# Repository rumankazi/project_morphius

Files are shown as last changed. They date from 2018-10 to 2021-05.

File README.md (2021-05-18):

# Project Morphius
The final year project of students of Electronics and Telecommunication department at Sardar Patel Institute of Technology, Mumbai.

An open source project under the guidance of Prof. Dr. Preetida V. Jani. 

Here you will find the required code files, design files, assembly and respective instructions.

Follow us on youtube: https://www.youtube.com/channel/UCsKmAn2daWavVmRRQK_fTjw

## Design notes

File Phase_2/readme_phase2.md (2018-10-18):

Arduino folder contains files required for testing. Also contains final code required for interfacing app and base module.

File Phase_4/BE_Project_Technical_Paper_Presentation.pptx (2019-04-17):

## Morphius

Self-configuring modular robot that navigates through cracks and debris for inspection

## Problem Statement

Use of modular robots for rescue operations involve constraints on parameters such as speed, size, shape of robot, locomotion mechanisms, etc. This requires development and design of a MRS that optimizes the above parameters. The use of heterogeneous modules capable of self-reconfiguration improves speed of locomotion and resourcefulness at the cost of simplicity.

## Existing Technology

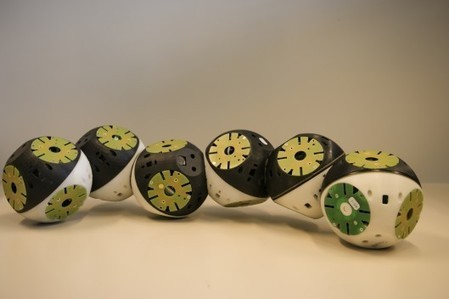
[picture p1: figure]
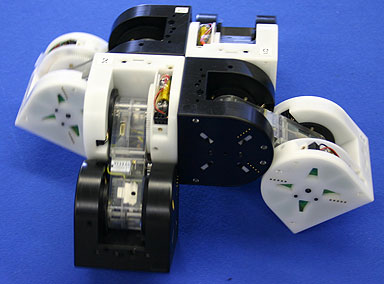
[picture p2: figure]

M-Tran - III

RoomBots

## Comparison

Existing Technology | Our technology
Relatively homogenous modules lacking in functionality | Heterogenous modules - tailored for use in disaster struck areas
Not practically deployable | Practically deployable
Designed for generalized applications - performance degrades | Problem oriented approach - provides better results
Expensive | Cost effective

## Limitations

- Not suited for rescue operations in disasters - earthquake, hurricane
- Difficult to deploy in disaster struck areas
- Less cost effective technology
- Not adaptable to different types of terrain or obstacles
- Lack decision making capability

## Proposed Solution

- Heterogenous modules - different functions tailored for our application
- Autonomous & self- reconfigurable
- Robust design for rough environment
- Providing map of the disaster struck area
- Adapts to the different terrain using different morphology

## Robotic System Structure

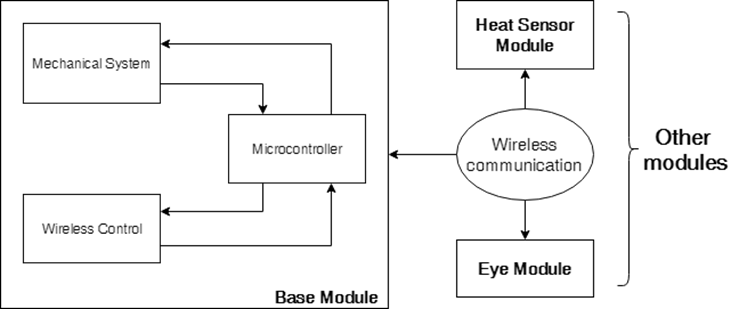
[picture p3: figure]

## Base Module Architecture

## Secondary Module Architecture

## Hardware & Software Assembly

Hardware:
- Atmega2560, Arduino Nano
- Wi-Fi
- Motor -
  - geared, 10kg stall torque, 100rpm
  - geared, quadrature encoder, 150rpm
  - Servo - 7kg at 1.5A, 6V
  - Micro DC motor - geared, 5kg torque
- Motor driver - L298n, L293d
- Bevel gears - 3D printed
- Wheels: 6.5cm, 10.9cm
- Pi Camera - 5MP

Software:
- Autodesk Fusion 360
- AutoCAD
- Opencv - python library
- Aruco - python library
- ArUco markers - 3cm x 3cm, 5x5 matrix size

## Aruco Detection

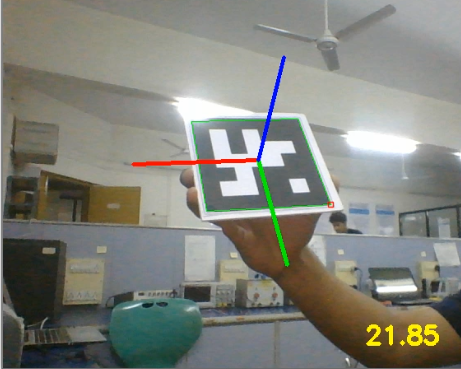
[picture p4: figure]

## Linking Mechanism

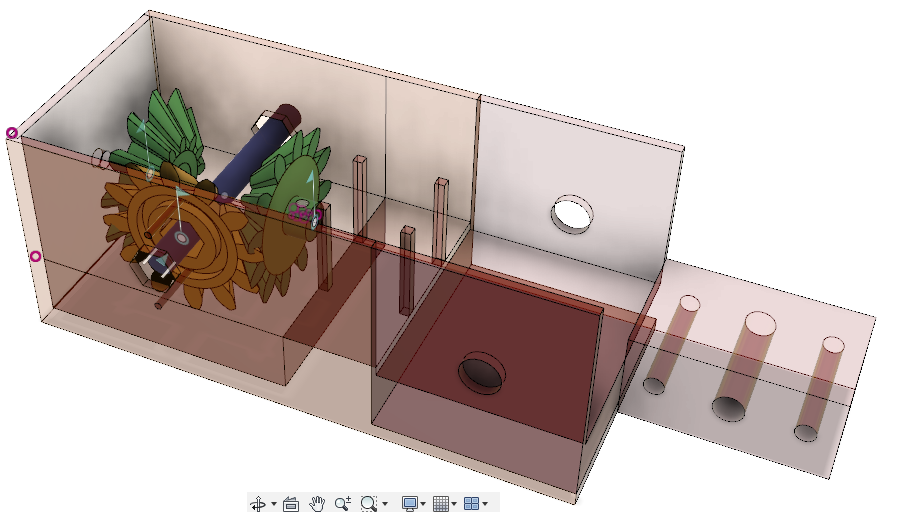
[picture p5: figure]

- 3 bevel gears - 3D printed
- 1 geared DC motor, 1 Servo motor
- Genderless connector - bolt

## Linking Mechanism

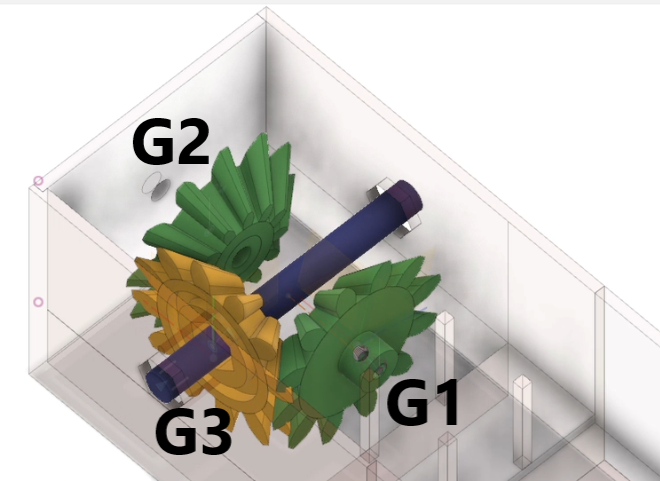
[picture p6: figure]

Closed Screw Mechanism

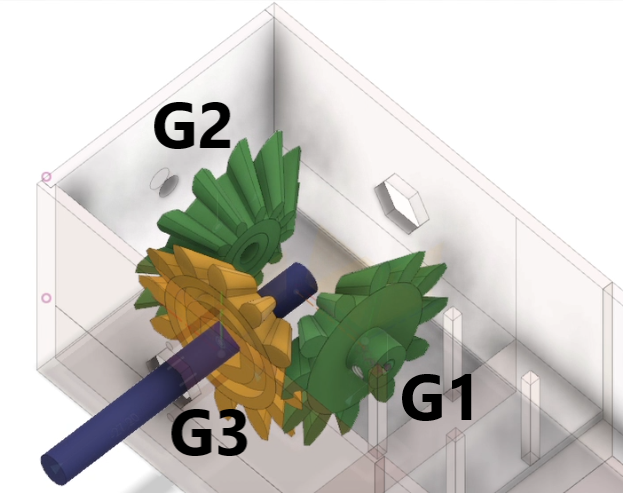
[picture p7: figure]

Open Screw Mechanism

## Result Analysis

- Tradeoff between size and speed for motors and wheels
- Alignment of wheels for stability and speed enhancement
- Sturdier actuation mechanism with minimum constraint
- Detection and alignment of modules for connection
- Chances of misalignment while engaging
- Size of the markers has to be minimized according to the smallest module

## Conclusion

- Speedy-modular-robots have potential to be used in rescue operations
- Speed control possible using PWM
- Decision making capability has been added to the modules
- ArUco Markers have improved the accuracy of alignment of two modules.
- Machine Learning can be used to improve performance over the period
- Sturdy modular design for rough terrains ensure protection of sensors

## Future Scope

- Using machine learning for configuration
- Improving the linking mechanism design and making it compact
- Using cloud for data collection and remote monitoring
- Development of different modules with different sensors

## Morphius Accessibility

Entire project is open source and is accessible to everyone.
All the instructions and required files are regularly updated on github and can be easily accessed using the following link:
https://github.com/rumankazi/project_morphius
YouTube Channel:
https://www.youtube.com/channel/UCsKmAn2daWavVmRRQK_fTjw

## References

1. M. Yim, D. G. Duff, and K. Roufas, “Modular reconfigurable robots, an approach to urban search and rescue,” in Proceedings of the 1st International Workshop on Human-friendly Welfare Robotics Systems, Taejon, Korea, 2000.
2. H. Ahmadzadeh, E. Masehian, and M. Asadpour, “Modular robotic systems: characteristics and applications,” Journal of Intelligent & Robotic Systems, vol. 81, no. 3-4, pp. 317–357, 2016.
3. H. Kurokawa, K. Tomita, A. Kamimura, S. Kokaji, T. Hasuo, and S. Murata, “Distributed self-reconfiguration of m-tran iii modular robotic system,” The International Journal of Robotics Research, vol. 27, no. 3-4, pp. 373–386, 2008.
4. J. Davey, N. Kwok, and M. Yim, “Emulating self-reconfigurable robots design of the smores system,” in 2012 IEEE/RSJ International Conference on Intelligent Robots and Systems (IROS). IEEE, 2012, pp. 4464–4469.
5. C. S. S. Reddy, A. Agrawal, K. Anupama et al., “Sq-bot-a modular robot prototype for self-reconfiguring structures,” in International Conference on Robotics: Current Trends and Future Challenges (RCTFC),. IEEE, 2016, pp. 1–6.

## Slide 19

6. J. Zhao, X. Cui, Y. Zhu, and S. Tang, “A new self-reconfigurable modular robotic system ubot: Multi-mode locomotion and self-reconfiguration,” in 2011 IEEE International Conference on Robotics and automation (ICRA). IEEE, 2011, pp. 1020–1025.
7. A. Spr¨owitz, R. Moeckel, M. Vespignani, S. Bonardi, and A. J. Ijspeert, “Roombots: A hardware perspective on 3d self-reconfiguration and locomotion with a homogeneous modular robot,” Robotics and Autonomous Systems, vol. 62, no. 7, pp. 1016–1033, 2014.
8. S. Chitta and J. Ostrowski, “Motion planning for heterogeneous modular mobile systems,” in ICRA’02. IEEE International Conference on Robotics and Automation, 2002. Proceedings., vol. 4. IEEE, 2002, pp. 4077–4082.
9. G. Hu, S. Huang, L. Zhao, A. Alempijevic, and G. Dissanayake, “A robust rgb-d slam algorithm,” in 2012 IEEE/RSJ International Conference on Intelligent Robots and Systems. IEEE, 2012, pp. 1714–1719.
10. “Raspberry Pi 3 Model B - Raspberry Pi.” [Online]. Available: https://www.raspberrypi.org/products/raspberry-pi-3-model-b/

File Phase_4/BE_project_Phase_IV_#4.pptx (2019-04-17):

## Morphius

Self-configuring modular robot that navigates through cracks and debris for inspection

## Problem Statement

Use of modular robots for rescue operations involve constraints on parameters such as speed, size, shape of robot, locomotion mechanisms, etc. This requires development and design of a MRS that optimizes the above parameters. The use of heterogeneous modules capable of self-reconfiguration improves speed of locomotion and resourcefulness at the cost of simplicity.

## Objectives

●Study of existing MRS (Phase 1)
●Development & Designing the structure of MRS (Phase 1-2-3)
●Inter-module mechanical connection Mechanism (Phase 3)
●Wireless Communication amongst the modules (Phase 2-3)
●Determining the best possible path and configuration (Phase 4)
●Improving the speed of MRS (Phase 4)

## Comparison

Existing Technology | Our technology
Relatively homogenous modules lacking in functionality | Heterogenous modules - tailored for use in disaster struck areas
Not practically deployable | Practically deployable
Designed for generalized applications - performance degrades | Problem oriented approach - provides better results
Expensive | Cost effective

## Robotic System Structure


## Base Module Architecture

## Secondary Module Architecture

## Limitations

- Not suited for rescue operations in disasters - earthquake, hurricane
- Difficult to deploy in disaster struck areas
- Less cost effective technology
- Not adaptable to different types of terrain or obstacles
- Lack decision making capability

## Proposed Solution

- Heterogenous modules - different functions tailored for our application
- Autonomous & self- reconfigurable
- Robust design for rough environment
- Providing map of the disaster struck area
- Adapts to the different terrain using different morphology

## Previous Work

- Backbone design of robot
- Working Prototype of base module
- Established wireless communication
- Power budgeting of single module
- Analysis of various connection mechanisms

## Previous Remarks

- Minimize the parameters to be controlled
- Weight Calculation
- Different wireless communication protocols testing
- Voltage v/s current rating for motors

## Progress Achieved - Phase 4

- Optimization of the design of the base module and secondary modules
- Selection of motors of locomotion with high stall torque (10kg)
- Prototype of connection mechanism
- 3D printing of the mechanism
- Image processing for identification and alignment
- Using Machine Learning for the terrain identification
- Study path planning and mapping algorithms

## Software Implementation

## Testing

Hardware:
- Atmega2560, Arduino Nano
- Bluetooth - HM10 , Xbee
- Motor -
  - geared, 10kg stall torque, 100rpm
  - geared, quadrature encoder, 150rpm
  - Servo - 7kg at 1.5A, 6V
  - Micro DC motor - geared, 5kg torque
- Motor driver - L298n, L293d
- Bevel gears - 3D printed
- Wheels -
  - (diameter)6.5cm, 10.9cm
  - Castor

Software:
- Autodesk Fusion 360
- AutoCAD
- Opencv - python library
- Aruco - python library
- ArUco markers - 14x14, 5x5 matrix size

## Actuation Mechanism


- 3 bevel gears - 3D printed
- 1 geared DC motor, 1 Servo motor
- Genderless connector - bolt

## Result Analysis

- Tradeoff between size and speed for motors and wheels
- Alignment of wheels for stability and speed enhancement
- Sturdier actuation mechanism with minimum constraint
- Detection and alignment of modules for connection
- Chances of misalignment while engaging
- Size of the markers has to be minimized according to the smallest module

## Further Planning

- Using machine learning for configuration
- Improving the linking mechanism design and making it compact
- Using cloud for data collection and remote monitoring
- Development of different modules with different sensors

## Morphius Accessibility

Entire project is open source and is accessible to everyone.
All the instructions and required files are regularly updated on github and can be easily accessed using the following link:
https://github.com/rumankazi/project_morphius
YouTube Channel:
https://www.youtube.com/channel/UCsKmAn2daWavVmRRQK_fTjw

## References

1. H. Ahmadzadeh, E. Masehian and M. Asadpour, "Modular Robotic Systems: Characteristics and Applications", Springer, Dordrecht, 2015.
2. Stoy, Kasper & Brandt, David & Christensen, David. (2010). Self-Reconfigurable Robots: An Introduction.
3. Haruhisa Kurokawa,Kohji Tomita, Akiya Kamimura, Shigeru Kokaji, Takashi Hasuo,Satoshi Murata , "Distributed Self-Reconfiguration of M-TRAN III Modular Robotic System ," in International Journal of Robotics March 2008
4. Jay Davey, Ngai Kwok and Mark Yim, "Emulating Self-reconfigurable Robots - Design of the SMORES System " in 2012 IEEE/RSJ International Conference on Intelligent Robots and Systems
5. Jie Zhao, Xindan Cui, Yanhe Zhu, et al. “A new self-reconfigurable modular robotic system UBot: Multi-mode locomotion and self-reconfiguration,” IEEE International Conference on Robotics and Automation. Piscataway, NJ, USA , pp. 1020-1025, 2011.
6. H. Ercan and P. Boyraz, "Design of a Modular Mobile Multi Robot System: ULGEN (Universal-Generative Robot)", IEEE Xplore, 2016.

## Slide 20

7. C. S. S. Reddy, S. patlolla, A. Agrawal and K. R. Anupama, "SQ-BOT - a modular robot prototype for self-reconfiguring structures," 2016 International Conference on Robotics: Current Trends and Future Challenges (RCTFC), Thanjavur, 2016, pp. 1-6.
8. S. Chitta and J. R. Ostrowski, "Motion planning for heterogeneous modular mobile systems," Proceedings 2002 IEEE International Conference on Robotics and Automation (Cat. No.02CH37292), Washington, DC, USA, 2002, pp. 4077-4082 vol.4
9. Andres Castano Wei-Min Shen Peter Will, "CONRO: Towards Deployable Robots with Inter-Robots Metamorphic Capabilities, " in Autonomous Robots June 2000, Volume 8, Issue 3, pp 309–324
10. R. Fitch, Z. Butler, D. Rus, "Reconfiguration planning for heterogeneous self-reconfiguring robots, " in 2003 IEEE/RSJ International Conference on Intelligent Robots and Systems (IROS 2003)
11. Shimizu, T. Kato, M. Lungarella and A. Ishiguro, "Adaptive Reconfiguration of a Modular Robot through Heterogeneous Inter-Module Connections", IEEE Xplore, 2008.

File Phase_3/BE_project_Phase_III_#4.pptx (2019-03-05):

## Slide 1

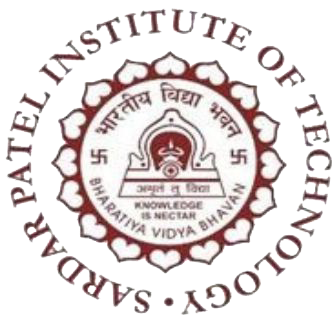
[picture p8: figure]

Sardar Patel Institute of Technology

Electronics and Telecommunication Department

B.E Project (ETP701)
Stage 2

Morphius : Self-reconfiguring modular robot that navigates through cracks and debris for inspection

A project under the guidance of
Dr. Preetida V-Jani

Group Number 4
Ruman Kazi
Ameya Nambisan
Simran Tiwari

## Problem Statement

Use of modular robots for rescue operations involve constraints on parameters such as speed, size, shape of robot, locomotion mechanisms, etc. This requires development and design of a MRS that optimizes the above parameters. The use of heterogeneous modules capable of self-reconfiguration improves speed of locomotion and resourcefulness at the cost of simplicity.

## Objectives

●Study of existing MRS (Phase 1)
●Development & Designing the structure of MRS (Phase 1-2-3)
●Inter-module mechanical connection Mechanism (Phase 3)
●Wireless Communication amongst the modules (Phase 2-3)
●Determining the best possible path and configuration (Phase 4)
●Improving the speed of MRS (Phase 4)

## Comparison

Existing Technology | Our technology
Relatively homogenous modules lacking in functionality | Heterogenous modules - tailored for use in disaster struck areas
Not practically deployable | Practically deployable
Designed for generalized applications - performance degrades | Problem oriented approach - provides better results
Expensive | Cost effective

## Robotic System Structure


## Base Module Architecture

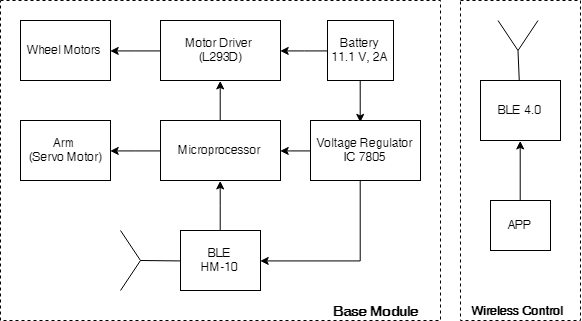
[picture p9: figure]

## Limitations

- Not suited for rescue operations in disasters - earthquake, hurricane
- Difficult to deploy in disaster struck areas
- Less cost effective technology
- Not adaptable to different types of terrain or obstacles
- Lack decision making capability

## Proposed Solution

- Heterogenous modules - different functions tailored for our application
- Autonomous & self- reconfigurable
- Robust design for rough environment
- Providing map of the disaster struck area
- Adapts to the different terrain using different morphology

## Previous Work

- Backbone design of robot
- Working Prototype of base module
- Established wireless communication
- Power budgeting of single module
- Analysis of various connection mechanisms

## Previous Remarks

- Minimize the parameters to be controlled
- Weight Calculation
- Different wireless communication protocols testing
- Voltage v/s current rating for motors

## Progress Achieved - Phase 3

- Optimization of the design of the base module
- Selection of motors of locomotion with high stall torque (10kg)
- Prototype of connection mechanism
- Image processing for identification and alignment
- Study path planning and mapping algorithms

## Actuation Mechanism


- 3 bevel gears - 3D printed
- 1 geared DC motor, 1 Servo motor
- Genderless connector - bolt

## Testing

Hardware:
- Atmega2560, Arduino Nano
- Bluetooth - HM10 , Xbee
- Motor -
  - geared, 10kg stall torque, 100rpm
  - geared, quadrature encoder, 150rpm
  - Servo - 7kg at 1.5A, 6V
  - Micro DC motor - geared, 5kg torque
- Motor driver - L298n, L293d
- Bevel gears - 3D printed
- Wheels -
  - (diameter)6.5cm, 10.9cm
  - Castor

Software:
- Autodesk Fusion 360
- AutoCAD
- Opencv - python library
- Aruco - python library
- ArUco markers - 14x14, 5x5 matrix size

## Result Analysis

- Tradeoff between size and speed for motors and wheels
- Alignment of wheels for stability and speed enhancement
- Sturdier actuation mechanism with minimum constraint
- Detection and alignment of modules for connection
- Chances of misalignment while engaging
- Size of the markers has to be minimized according to the smallest module

## Further Planning

- Phase 4 (First week of April):
  - Development of other connectable heterogeneous modules
  - Algorithm for deciding optimal path and configuration
  - Development of reconfiguration algorithm

## Morphius Accessibility

Entire project is open source and is accessible to everyone.
All the instructions and required files are regularly updated on github and can be easily accessed using the following link:
https://github.com/rumankazi/project_morphius
YouTube Channel:
https://www.youtube.com/channel/UCsKmAn2daWavVmRRQK_fTjw

## References

1. H. Ahmadzadeh, E. Masehian and M. Asadpour, "Modular Robotic Systems: Characteristics and Applications", Springer, Dordrecht, 2015.
2. Stoy, Kasper & Brandt, David & Christensen, David. (2010). Self-Reconfigurable Robots: An Introduction.
3. Haruhisa Kurokawa,Kohji Tomita, Akiya Kamimura, Shigeru Kokaji, Takashi Hasuo,Satoshi Murata , "Distributed Self-Reconfiguration of M-TRAN III Modular Robotic System ," in International Journal of Robotics March 2008
4. Jay Davey, Ngai Kwok and Mark Yim, "Emulating Self-reconfigurable Robots - Design of the SMORES System " in 2012 IEEE/RSJ International Conference on Intelligent Robots and Systems
5. Jie Zhao, Xindan Cui, Yanhe Zhu, et al. “A new self-reconfigurable modular robotic system UBot: Multi-mode locomotion and self-reconfiguration,” IEEE International Conference on Robotics and Automation. Piscataway, NJ, USA , pp. 1020-1025, 2011.
6. H. Ercan and P. Boyraz, "Design of a Modular Mobile Multi Robot System: ULGEN (Universal-Generative Robot)", IEEE Xplore, 2016.

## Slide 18

7. C. S. S. Reddy, S. patlolla, A. Agrawal and K. R. Anupama, "SQ-BOT - a modular robot prototype for self-reconfiguring structures," 2016 International Conference on Robotics: Current Trends and Future Challenges (RCTFC), Thanjavur, 2016, pp. 1-6.
8. S. Chitta and J. R. Ostrowski, "Motion planning for heterogeneous modular mobile systems," Proceedings 2002 IEEE International Conference on Robotics and Automation (Cat. No.02CH37292), Washington, DC, USA, 2002, pp. 4077-4082 vol.4
9. Andres Castano Wei-Min Shen Peter Will, "CONRO: Towards Deployable Robots with Inter-Robots Metamorphic Capabilities, " in Autonomous Robots June 2000, Volume 8, Issue 3, pp 309–324
10. R. Fitch, Z. Butler, D. Rus, "Reconfiguration planning for heterogeneous self-reconfiguring robots, " in 2003 IEEE/RSJ International Conference on Intelligent Robots and Systems (IROS 2003)
11. Shimizu, T. Kato, M. Lungarella and A. Ishiguro, "Adaptive Reconfiguration of a Modular Robot through Heterogeneous Inter-Module Connections", IEEE Xplore, 2008.

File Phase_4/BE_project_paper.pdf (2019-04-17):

# Morphius: A Self-configuring modular robot that navigates through cracks and debris for inspection

Abstract—Modular robots are made up of mechanically constrained smaller robots with different degrees of freedom. These smaller robots can either detach or attach together to get a desired structure or configuration. The existing technology in this field consists of robots with homogeneous modules that lack the decision making capability and are not currently applicable in disaster struck area for inspection.
To improve their performance, heterogeneity has been introduced in its structure making it possible to design versatile, application tailored modules having decision making capability. Each module will independently be able to perform a specific task depending on the attributes and given characteristics with self-configuring and reconfiguring capability. At the same time all the modules communicate and share their data with each other to collectively accomplish the goal. We have also introduced wheels for effective and faster locomotion and self-docking capability using a neutral connector. This paper addresses the two main challenges while developing such modular robotic system
- intelligence and speed, in the field of rescue operations with adaptive morphology.
Keywords—Modular robot, Self configurable, Heterogeneity, Self-docking, Wireless communication, Autonomous, ArUco markers.
I. INTRODUCTION

In the past two decades around 10 lakh deaths have been reported worldwide due to earthquakes, landslides, storms and hurricanes; almost 1.5 lakhs were only from India. Over 15% of these were late deaths - deaths due to injuries that become prominent with the passage of time - could have been avoided had disaster management been more efficiently carried out. Doctors refer to this time as the golden hour, which is the period of time after a traumatic incident during which immediate medical assistance can save a person’s life. Some injuries like haemorrhage, brain injuries and internal bleeding deteriorate rapidly. So it is necessary to keep the time lag between injury and treatment bare minimum.
Rescue operations conducted worldwide mostly employ trained professionals and dogs. Equipment such as video cameras and high sensitivity listening devices are used in order to locate a person moving or responding to rescuers calls [1]. Depending on the scale of destruction, the process of extrication can extend over 24 hours. These environments pose a risk to even the lives of rescuers as there is imminent danger of a further collapse in event of an earthquake. Recent reports prove the usefulness of robots in these fields as they enable rescuers to analyse the environment remotely. They had better speed and did not require much manpower. But because of their large size and power requirements, these robots are not efficient enough. This is where the concept of multi robot systems can be used. Due to the increasing demands in functionality, adaptability and robustness engineering innovations brought forth the idea of multi robot systems - systems which work in a distributed manner to complete a task. Inspired by biological systems, scientists proposed the use of self organising modular robotic system [2].
Through this paper we try to overcome the problems related to intelligence, speed and increased locomotion. Morphius aims to deal with the surrounding environment specifically targeting disaster struck areas and would try to utilize its functions for the assisting the rescue operation.

II. LITERATURE SURVEY

The most important thing in a rescue operation is the speed at which the help arrives to the victims. Flexibility to reach the remote location is another key aspect which decides the efficiency rescue operations and rate at which the injured people are provided with medical care. The technology has been consistently evolving toward providing a solution for such scenarios. There have been multiple attempts to provide a robotic solution to such areas. There are key terms associated with such systems. The research is required to go through all the attempts that have been made and to step upon already developed solutions and rectify their limitations and faults to make them efficient and better the desired application.

A. Basic terminology & concepts related to MRS
To understand already developed series of modular robots, it is important to understand the key terms and definitions related to modular robotic systems (MRS). Modular Robotic Systems: Characteristics and Applications - A detailed report [2] covers overall terminology related to the MRS and also provides key insights in the domain of modular-robotics. The four fundamental components that define a modular robotic systems are ”Module, Information, Task and Environment (MITE)” [2]. This report also discusses about the problems associated with certain systems and their feasibility.
It is also necessary to classify the robotic system in standardized format depending on the four components (MITE) [2]. We can create different types of MRS by varying these components. There are about 94 [2] developed modular robots existing today each one having unique features and mechanism.
B. Existing MRS
Existing technologies include M-TRAN III [3], SMORES [4], SQ-BOT [5], UBot [6] among many others and have distinctive features like size, locomotion mechanism, structure, behaviour etc. Analysis of different existing modular robotic systems provides different perspective with which a particular problem was solved. Analysing the particular problem and designing the system accordingly by considering the variable, dependent and independent parameters is the key to get an optimum MRS. Following are two of the most advanced MRS existing today.
1) M-TRAN III: Design inspired by locomotion of reptiles, M-TRAN III [3] was developed in 2007 as a successor of M-TRAN II (2003) and original M-TRAN (2000). Homogeneous modules made of same shape and mechanism to connect. It uses most of modern technology of wireless communication through its different modules. The shape of each module gives M-TRAN [3] huge flexibility of different morphologies by combining itself with other similar modules.. Because of reptile locomotion, M-TRAN is comparatively slower than others.
2) Room Bots: EPFL University project developed for different morphology and heavy lifting. The design is sturdy, large and can hold up large weights. Room bots are helpful in heavy load lifting and can be used to transport heavy loads. Room bots [7] have lesser flexibility compared to M-TRAN III [3]. Because of the heavy torque lifting motors, room bots have to compromise on the size of each module. As the size increases, it reduces the probability of going through narrow holes and cracks.
M-TRAN III [3] compromised on speed to get more flexibility, whereas Room Bots compromised on size of each module to get more heavy lifting. Each modular robotic system has to find a balanced system to solve a certain problem. For a particular application we can compromise on the components that won’t affect the performance of the system as much. The existing systems are not deployable in practical environments due to constraints on their locomotion and/or structure. And those which can be employed in such conditions are either expensive, slow and lack the decision making capability. If we can provide a solution by bypassing such factors, we can achieve our desired goal.

III. SYSTEM DESIGN

The basic block diagram of Morphius’ modular robotic system is as shown in the figure 1. The number of modules to be included is variable and will be decided by the desired application. Currently we are working with one eye module for testing and prototyping purpose. But it can be extended to multiple modules having different sensors and actuators. This block diagram just represents how it will interact with the base module which will be driving the modules when necessary. The software part comprises of the use of 5x5 ArUco markers for identifying a particular module and also for aligning the module for proper linking. The pi-camera at the front of every module detects the ArUco marker on the module it needs to be attached to. The marker is used for uniquely identifying the module, calculate its distance and estimate its

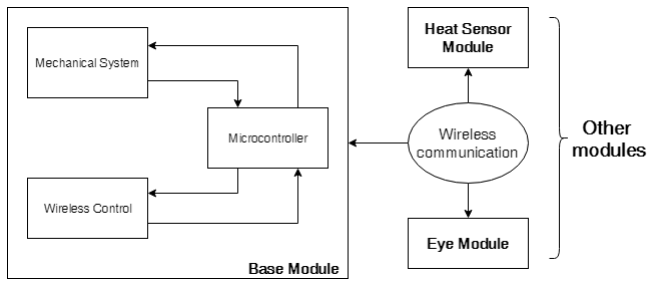
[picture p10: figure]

Fig. 1: Block diagram of the system

pose. This information is used to align the modules as they come closer to each other to be linked.
The eye module consists of a camera with high resolution. This camera is primarily used for mapping the area besides helping the robot to plan its path [8]. This is done using a visual Simultaneous Localisation And Mapping (SLAM) algorithm [9]. A set of points in the Region Of Image (ROI) are tracked through successive frames to estimate the relative position of the module so that it creates a map of its surrounding terrain. Images from the camera can also be monitored in real time on the network. The eye module is also used to identify the type of terrain and determine whether it can move forward or not. The module is trained to identify the terrain using classification with the help of a convolutional neural network.

IV. HARDWARE ASSEMBLY

The block diagram of configuration of components involved in base module is as shown in the figure 2a. The base module includes microprocessor to control the base module which receives signal from other modules (Figure 2b) via WiFi. The dimensions of this module are bigger compared to the other module so that it is stable enough to lift other modules linked together. The structure of the modules are made out of 3mm acrylic sheets and the mechanical connection mechanism is 3D printed out of Polylactic acid (PLA) fiber. The basic components used are:
- Motors:
– DC gear motor with 100 RPM and a high stalling torque was used for the base module. For other modules this is replaced by low torque compact motors.
– A servo motor having high torque of 5KG used for arm mechanism such that it can lift heavy modules. In case of eye module servo will also be used to pan the camera.
– Micro gear DC motor with 100 RPM and a high torque for the linking mechanism.
- Microprocessor:
– Raspberry Pi model 3B [10] which has a Quad Core 1.2GHz Broadcom BCM2837 64bit CPU [10] was used as our central processor.

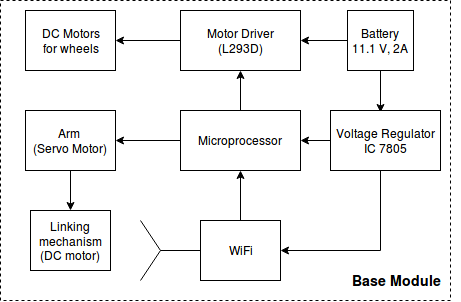
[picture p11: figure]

(a) Base module

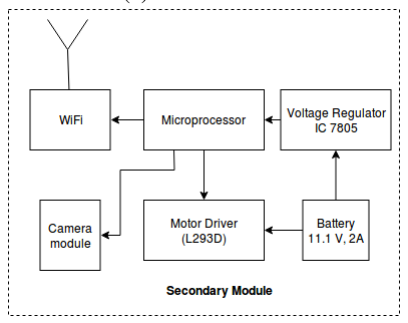
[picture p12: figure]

(b) Secondary Module

Fig. 2: Block Diagrams of the modules

– Controls pwm for Servo and Wheel motors. Also receives messages through WiFi. It also implements machine learning and image processing for aligning the modules.
– This board was chosen as CPU for each module for the machine learning and image processing to be done through python. We can use any PyBoard having python modules and opencv libraries.
- Battery:
– Lithium-Ion rechargeable battery providing 11.1V and 2Amps of current
– Used as power of source for entire module and will power servo, microprocessor, motor driver, Wi-Fi and respective sensors.
- Voltage Regulator:
– IC7805 was used to provide 5V supply to the microprocessor from the supply of 11.1V battery
– Also provides supply to DC motors used for wheels and Servo Motor
- WiFi:
– In-built WiFi on the Raspberry Pi 3B model was used for communication.
– Better than Bluetooth in terms of coverage, connectivity and speed.
– Advantage is we can remotely access all the modules remotely once they are set on same network.
- ArUco Markers:
– Augmented Reality Marker (ArUco) is a marker consisting of black and white matrix denoting 0 and
1. And it can store information in this matrix (Figure 4)(4x4, 5x5, etc.).

– We are using 5x5 matrix with different IDs for identifying each module uniquely.
– These markers are also used for pose estimation and distance calculation between any two modules. These markers help each module to align themselves with respect to the other module.

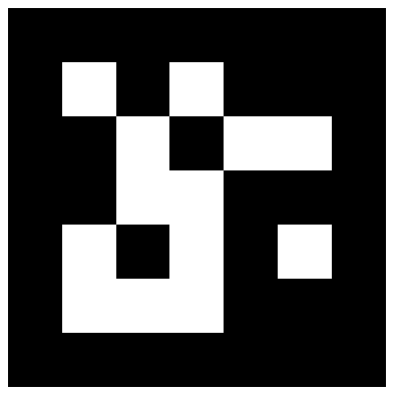
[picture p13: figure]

Fig. 3: An ArUco Marker of 5x5 Matrix with ID = 0

- Camera
– A pi-camera used by all modules and would be used for detection of aruco markers. And then it will send signals to CPU, which will relay signals to motors for correct alignment with other module.
– A webcam or a camera with at least 2Mp resolution for mapping only on the eye module.
- IR sensor:
– For obstacle detection and path planning. It is also used to calculate the height of the obstacle.
- Wheels
– 106mm Diameter and 44mm thick wheels for the base module to enhance the stability
– 70mm Diameter and 21mm thick wheels for the other modules to make them compact.
– Castor wheels for providing stability to the smaller modules.

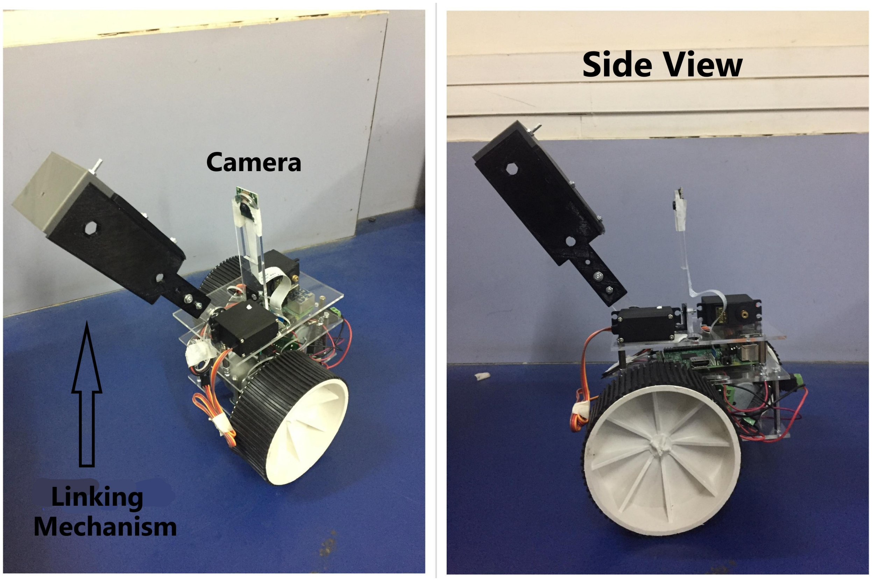
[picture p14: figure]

Fig. 4: Assembled Base Module with Linking Mechanism

V. LINKING MECHANISM
The key part of any Modular Robotic System(MRS) is its linking mechanism. Depending on the application of the MRS, the mechanism is decided. The key parameters involved while deciding a linking mechanism are:
- Weight of each module.
- Working environment.
- Size of the module.
- Algorithm for the configuration.
For Morphius, the surrounding environment is a rough terrain having uneven surfaces, debris and cracks. Also, Morphius should have maximum speed possible while traversing through such area. So, if we remove constraints on the size of the module and use high torque sturdy motors with strong body, we will require a physical linking mechanism to hold each module firmly throughout its operation.
The mechanism used has been shown in the figure 5. It comprises of three bevel gears(G1,G2 and G3) and one micro geared DC motor. The DC geared micro-motor is attached to one of the bevel gears(G1) which in turn rotates the main gear which has a bolt at its shaft. The rotating gear causes the bolt to move back and forth allowing it to lock into the arm of the other module. This entire mechanism is mounted inside a casing - 3D printed - using PLA material. Polylactic acid or PLA. This entire assembly is attached to a servo on the base module which helps align the arm in the z direction.

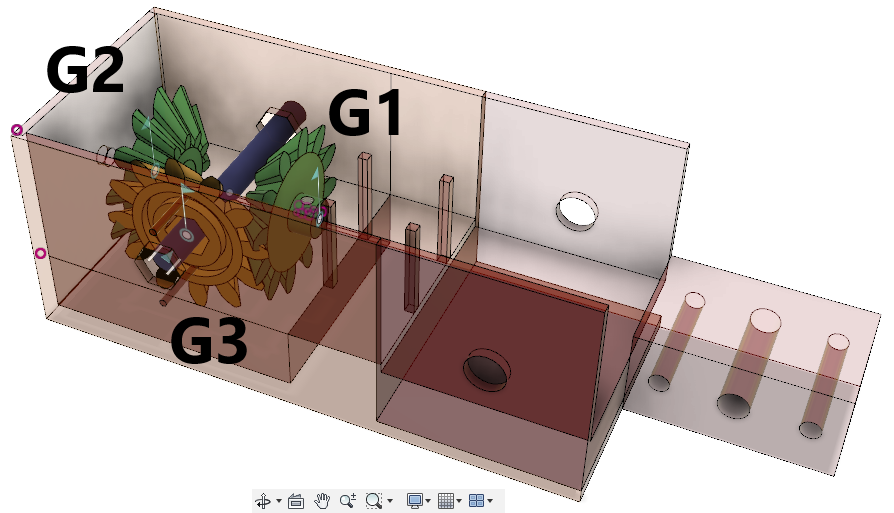
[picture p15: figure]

Fig. 5: The 3D printing parts of the linking mechanism

VI. TESTING AND ANALYSIS
Each module of Morphius can independently work on its own and can gather vital information. But in some cases it might require other modules to overcome an obstacle or to gather some extra data. In that case the linking mechanism plays a vital role in joining any two modules.
The linking part of one module needs to be perfectly aligned with the other module’s linking part in order to link with each other. For this we used ArUco Markers for perfect alignment of the bots in 3D space. ArUco Markers provide us exact location and orientation of the bot in 3D space (Figure 6). With the feedback from the camera, CPU provides signals to respective motors (wheels for x-y plane and servo for z-plane) and it aligns itself with the other module.
After aligning with the other module, actuation mechanism starts. The micro-motor situated inside the mechanism will start rotating the bevel gear(G1) and it will turn G3, this will result in the unwinding the screw (Figure 7) . After some time the screw will come out completely (Figure 8) and if the other


Fig. 6: Pose estimation using ArUco Marker in 3D space.

module was in correct position with the module, the screw will enter the other module and similarly the screw from the other module will enter this module. They both will lock each other and form a physical connection.

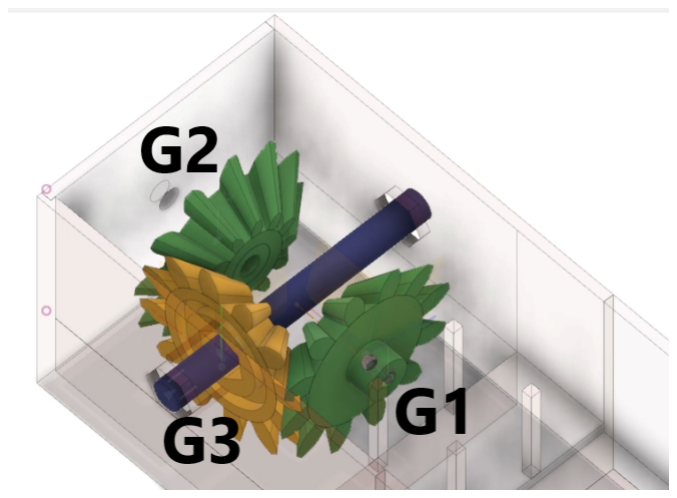
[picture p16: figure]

Fig. 7: Screw in closed position inside the mechanism.

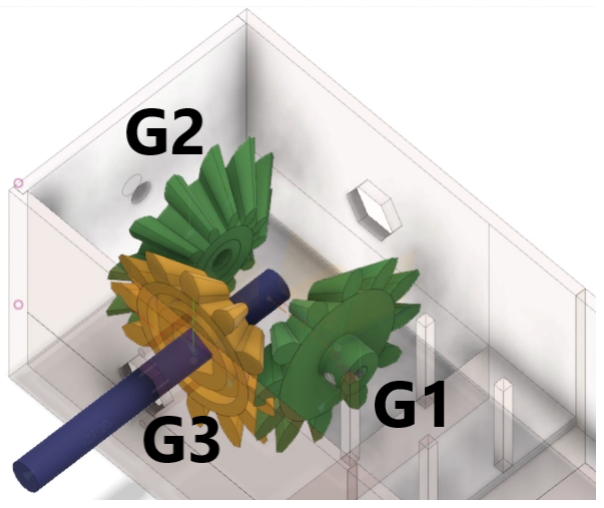
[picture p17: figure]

Fig. 8: Screw in opened position outside the mechanism.

This mechanism can handle heavy weights (up to 7Kg) without creating any hindrance to the locomotion of the module. The weight balance of the entire module has been correctly modified in order to avoid toppling even after lifting other modules.

VII. CONCLUSION
The results of the work done on Morphius show us the potential in the speedy-modular-robots that can be used in rescue operations. The work yielded a prototype of Morphius having two modules. The shifted axis of the bot has not compromised the stability yet provided a compact design. The speed of motors have been limited to 100RPM can be controlled depending on the type of the terrain using PWM (Pulse Width Modulation). The time required for establishing a physical link between two modules has reduced considerably with the help of ArUco Markers and Cameras. It also uses image processing and machine learning for analysing the type of terrain and deciding the morphology.
Morphius can be deployed in the rough terrains of disaster struck areas to gather vital data which can be extremely helpful in speedy rescue operations. The developed prototype has sturdy mechanism as well as sturdy structure to handle wear and tear over long duration. With decision making capability and improved speed in linking mechanism and in locomotion, Morphius has shown that modular robots are now ready to be deployed in real life scenarios to assist humans.

VIII. FUTURE SCOPE
The modules can be comprised of different additional sensors and actuation mechanisms such as grippers in order to perform certain tasks. Heterogeneity is essential in such applications as they increase the accessibility and functionality of the system. This idea can be exploited with the help of Morphius. Different processors can be used to improve the processing speed, to improve data mining as well as increasing the accuracy. If 3D printers with better resolutions are used, the linking mechanism can be made more compact and precise. Morphius has been kept as an open source project and is open for further future developments. A basic structure has been provided with necessary software and hardware. The proposed MRS provides a platform for developers to develop different modules with help of the base modules.

REFERENCES

[1] M. Yim, D. G. Duff, and K. Roufas, “Modular reconfigurable robots, an approach to urban search and rescue,” in Proceedings of the 1st International Workshop on Human-friendly Welfare Robotics Systems, Taejon, Korea, 2000.
[2] H. Ahmadzadeh, E. Masehian, and M. Asadpour, “Modular robotic systems: characteristics and applications,” Journal of Intelligent & Robotic Systems, vol. 81, no. 3-4, pp. 317–357, 2016.
[3] H. Kurokawa, K. Tomita, A. Kamimura, S. Kokaji, T. Hasuo, and
S. Murata, “Distributed self-reconfiguration of m-tran iii modular robotic system,” The International Journal of Robotics Research, vol. 27, no. 3-4, pp. 373–386, 2008.
[4] J. Davey, N. Kwok, and M. Yim, “Emulating self-reconfigurable robotsdesign of the smores system,” in 2012 IEEE/RSJ International Conference on Intelligent Robots and Systems (IROS). IEEE, 2012, pp. 4464–4469.
[5] C. S. S. Reddy, A. Agrawal, K. Anupama et al., “Sq-bot-a modular robot prototype for self-reconfiguring structures,” in International Conference on Robotics: Current Trends and Future Challenges (RCTFC),. IEEE, 2016, pp. 1–6.
[6] J. Zhao, X. Cui, Y. Zhu, and S. Tang, “A new self-reconfigurable modular robotic system ubot: Multi-mode locomotion and self-reconfiguration,” in 2011 IEEE International Conference on Robotics and automation (ICRA). IEEE, 2011, pp. 1020–1025.
[7] A. Sprowitz, R. Moeckel, M. Vespignani, S. Bonardi, and A. J. Ijspeert, ¨ “Roombots: A hardware perspective on 3d self-reconfiguration and locomotion with a homogeneous modular robot,” Robotics and Autonomous Systems, vol. 62, no. 7, pp. 1016–1033, 2014.
[8] S. Chitta and J. Ostrowski, “Motion planning for heterogeneous modular mobile systems,” in ICRA’02. IEEE International Conference on Robotics and Automation, 2002. Proceedings., vol. 4. IEEE, 2002, pp. 4077–4082.
[9] G. Hu, S. Huang, L. Zhao, A. Alempijevic, and G. Dissanayake, “A robust rgb-d slam algorithm,” in 2012 IEEE/RSJ International Conference on Intelligent Robots and Systems. IEEE, 2012, pp. 1714–1719.
[10] “Raspberry Pi 3 Model B - Raspberry Pi.” [Online]. Available: https://www.raspberrypi.org/products/raspberry-pi-3-model-b/

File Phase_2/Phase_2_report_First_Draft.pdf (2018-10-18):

Project report
on
Morphius: A Self-reconfiguring modular robot that navigates through cracks and debris for inspection

Submitted in partial fulfillment of the requirement for the award of the degree of

Bachelor of Engineering
in
Electronics & Telecommunications Engineering

by
Kazi Ruman
Nambisan Ameya
Tiwari Simran

under the guidance of

Dr. Preetida V. Jani

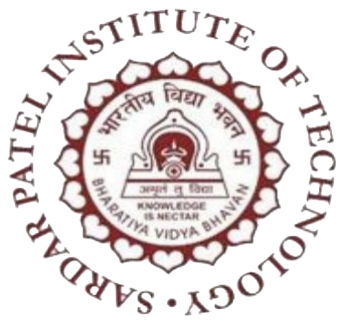
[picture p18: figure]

Department of Electronics & Telecommunication Engineering

Bharatiya Vidya Bhavan’s
Sardar Patel Institute of Technology Munshi Nagar, Andheri-West, Mumbai-400058

### Abstract

Modular robots are essentially arrays of kinematically-constrained simple robots with few degrees of freedom. They can attach to or detach from each other and form a modular structure or a configuration as per the need. There are many conceivable applications of modular robots in fields like space exploration, automation, consumer products, and so forth.

Our primary goal is to narrow down on problems in rescue operations in disaster zones which include inspection, rescue, exploration, mapping and navigation. The existing technology in this field consists of robots with homogenous modules which are not currently able to be used in disaster struck area for inspection of the area. To improve their performance, we introduce heterogeneity in its structure making it possible to design versatile, application tailored modules. Each module will independently be able to perform a specific task depending on the attribute/characteristic given. At the same time all the modules will communicate and share their data with each other to collectively accomplish the goal.

Morphius : A self-reconfiguring modular robot

### Contents

1 Introduction | 1
2 Literature Survey | 3
3 Problems in current technology | 6
4 Proposed Solution | 7
5 System Design | 8
6 Progress | 10
7 Further Planning | 11

ii

Morphius : A self-reconfiguring modular robot

### List of Figures

iii

Morphius : A self-reconfiguring modular robot

### 1 Introduction

### 1.1 Motivation

In the past two decades around 10 lakh deaths have been reported worldwide due to earthquakes, landslides, storms and hurricanes and almost 1.5 lakhs were only from India. Over 15% of these were late deaths - deaths due to injuries that become prominent with the passage of time - could have been avoided had disaster management been more efficiently carried out. Doctors refer to this time as the golden hour, which is the period of time after a traumatic incident during which immediate medical assistance can save a person’s life. Some injuries hemorrhage, brain injuries and internal bleeding deteriorate rapidly. So it is necessary to keep the time lag between injury and treatment bare minimum.

Rescue operations conducted worldwide mostly employ trained professionals and dogs. Equipments such as video cameras and high sensitivity listening devices are used in order to locate a person moving or responding to rescuers calls.[9] Often holes are dug to allow these devices to be inserted through obstructing walls and debris. Further the process of extrication takes longer making the entire process to extend to over 24 hours, depending on the scale of destruction. These environments pose a risk to even the lives of rescuers as there is imminent danger of a further collapse especially in case of earthquakes which may be followed by aftershocks. Recent reports prove the usefulness of robots in these fields as they enable rescuers to analyse the environment remotely. They had better speed and did not require much manpower. But because of their large size and power requirements, these robots are not efficient enough. This is where the concept of multi robot systems can be used. Due to the increasing demands in functionality, adaptability and robustness engineering innovations

1

Morphius : A self-reconfiguring modular robot

brought forth the idea of multi robot systems - systems which work in a distributed manner to complete a task. These robots too had limitations because of their fixed shapes and sizes. Inspired by biological systems, scientists proposed the use of self organizing modular robotic system.[1]

### 1.2 Objectives

Aim of developing ’Morphius’ is to provide a suitable faster assistance for the rescue operations in disaster struck areas such as tornadoes and earthquakes. So, we divided the project into discrete objectives. The objectives of our project include:

- Designing of a Modular Robotic System (MRS) with heterogeneous modules.
- Development of a robust inter-module connection mechanism for the modules such that exerted shear forces are endured.
- Establishing wireless communication between modules such that maximum coverage area is achieved.
- Determining the best possible path and configuration for each scenario while completing the rescue operation.
- Improving the speed of MRS by using wheels for locomotion and minimising the number of transformations required to achieve a configuration.
- Attributing decision making capability so that the robot becomes autonomous and only needs human surveillance.

2

Morphius : A self-reconfiguring modular robot

### 2 Literature Survey

The most important thing in a rescue operation is the speed at which the help arrives to the victims. Flexibility to reach the remote location is another key aspect which decides the efficiency rescue operations and rate at which the injured people are provided with medical care. The technology has been consistently evolving toward providing a solution for such scenarios. There have been multiple attempts to provide a robotic solution to such areas. There are key terms associated with such systems. The research is required to go through all the attempts that have been made and to step upon already developed solutions and rectify their limitations and faults to make them efficient and better the desired application.

### 2.1 Basic terminology & concepts related to MRS

To understand already developed series of modular robots, it is important to understand the key terms and definitions related to modular robotic systems(MRS). “Modular Robotic Systems: Characteristics and Applications - A detailed report ”[1] covers overall terminology related to the MRS and also provides key insights in the field of modular robotics. The four fundamental components that define a modular robotic systems are Module, Information, Task and Environment (MITE). This report also discusses about the problems associated with certain systems and their feasibility.

It is also necessary to classify the robotic system in standardized format depending on the four components (MITE)[1]. We can create different types of MRS by varying these components. There are about 94 developed modular robots existing today each one having unique features and mechanism.

3

Morphius : A self-reconfiguring modular robot

### 2.2 Existing MRS

Analysis of different existing modular robotic systems provides different perspective with which a particular problem was solved. Analyzing the particular problem and designing the system accordingly by considering the variable, dependent and independent parameters is the key to get an optimum MRS. Following are two of the most advanced MRS existing today.

### 2.2.1 M-TRAN III:

Design inspired by locomotion of reptiles, M-TRAN III [5]was developed in 2007 as a successor of M-TRAN II (2003) and original M-TRAN (2000). Homogeneous modules made of same shape and mechanism to connect. It uses most of modern technology of wireless communication through it’s different modules.


Figure 1: M-TRAN III[5]

The shape of each module gives M-TRAN huge flexibility of different morphologies by combining itself with other similar modules.. Because of reptile locomotion, M-TRAN is comparatively slower than others.

4

Morphius : A self-reconfiguring modular robot

### 2.2.2 Room Bots:

EPFL University project developed for different morphology and heavy lifting. The design is sturdy, large and can hold up large weights. Room bots are helpful in heavy load lifting and can be used to transport heavy loads. Room bots[8] have lesser flexibility compared to M-TRAN III. Because of the heavy torque lifting motors, room bots have to compromise on the size of each module. As the size increases, it reduces the probability of going through narrow holes and cracks.


Figure 2: Room bots[8]

As we can see, M-TRAN III compromised on speed to get more flexibility, whereas Room Bots compromised on size of each module to get more heavy lifting. Each modular robotic system has to find a balanced system to solve a certain problem. For a particular application we can compromise on the components that won’t affect the performance of the system as much. If we can provide a solution by bypassing such factors, we can achieve our desired goal.

5

Morphius : A self-reconfiguring modular robot

### 3 Problems in current technology

Existing technologies include M-TRAN III[5], SMORES[3], SQ-BOT[6], UBot[10] among many others and have distinctive features like size, locomotion mechanism, structure, behaviour etc. For example, CONRO[2] modules which are small, self-sufficient and relatively homogeneous module and have automatic inter-locking capabilities. They can change their configurations in a very short time but their locomotion is not suited for the environmental conditions of the problem stated. They lack the decision making capabilities and consist of relatively homogeneous modules which decreases the number of distinct configurations the robot can attain.

Heterogeneity is essential in such applications as they increase the accessibility and functionality of the system. Having modules of different sizes and with different attributes makes the system cost effective and reliable at the cost of algorithm complexity. The existing systems are not deplorable in practical environments due to constraints on their locomotion and/or structure. And those which can be employed in such conditions are either expensive, slow and lack the decision making capability. Thus there is a requirement of a cost-effective and robust design for the application.

6

Morphius : A self-reconfiguring modular robot

### 4 Proposed Solution

The key objective of our project is to design a modular robot tailored for our application. This system will have heterogeneous modules
- each with a specialized function and shape. This enables the robot to maintain its versatility allowing it to be used in similar scenarios like rescuing people in earthquake, landslide or hurricane struck area by navigating through the debris. The different sizes increase their mobility and accessibility which is of utmost importance in such sensitive areas.

Also each module can operate independently provides us with an extra degree of freedom. These modules can communicate the information gathered with other modules and reconfigure themselves as per the need. A trade-off, tailored for our application, will be achieved between algorithm complexity, reconfiguration time and increased functionality.[4][7] Thus making the robot resourceful at the same time more cost effective.

Key features of Morphius:

- Self-reconfigurable
- Improved speed
- Increased size flexibility
- Inter module communication
- Decision making capability
- Independent self-sustainable modules

7

Morphius : A self-reconfiguring modular robot

### 5 System Design

The present system includes microprocessor to control the base module which receives signal from an app via bluetooth low energy - BLE. Rechargeable Lithium-Ion battery was chosen so that bot can work for long duration and can be recharged again.

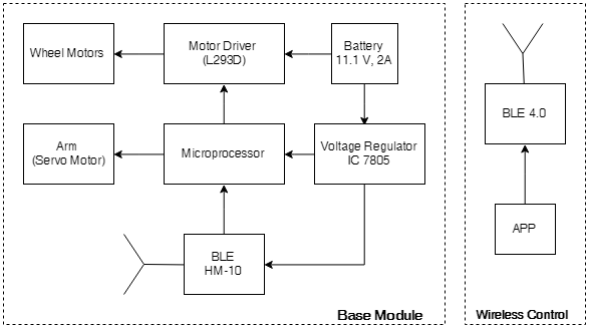
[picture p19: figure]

Figure 3: Block Diagram of the system

- Motors:

– Single BO Motor used for the main locomotion of first prototype. Fast and lightweight hence, suitable.

– A servo motor having high torque of 5KG used for arm mechanism such that it can lift heavy modules.

- Battery:

– Lithium-Ion rechargeable battery providing 11.1V and 2Amps of current.

– Used as power of source for entire base module.

8

Morphius : A self-reconfiguring modular robot

- Voltage Regulator:

– IC7805 was used to provide 5V supply to the microprocessor from the supply of 11.1V battery.

– Also provides supply to BO motors, BLE and Servo Motors

- BLE (Bluetooth Low Energy):

– HM-10 mudule for BLE was used. Based on Bluetooth 4.0

– Consumes very less energy, fasteer and better than HC-05

- Microprocessor:

– Arduino NANO based on ATMEGA was used as the central microprocessor.

– Controls pwm for Servo and Wheel motors. Also receives messages through BLE.

- App:

– Built in library of EVO was used for app development

– Provides UI interface to control the base module

– Sends integer values to Microprocessor via BLE

How does it work?

- These are the steps the system follows:
1. BLE on the base module and phone’s bluetooth get paired
2. App sends a signal in the form of integers through phone’s BLE
3. Microprocessor receives signal throgh BLE and compares it
4. Output according given out by the microprocessor on output pins
5. The output pins connected to different modules and motors respond accordingly

9

Morphius : A self-reconfiguring modular robot

### 6 Progress

In this stage our focus has been on the hardware implementation of the system. Using the MITE framework, different hardware components required for our application was examined. The following objectives have been worked upon:

- The backbone design of the system has been developed after considering different features from existing technologies.
- A prototype of the base module was developed in order to understand and analyze the structural stability and the complexities involved.
- Speed, acceleration and deceleration optimization for smoother locomotion
- Wireless communication between the module and android application has been tested.
- Power budgeting of a single module
- Various connection mechanisms to enhance the robustness of the structure were analyzed

Problems faced

- Balancing Center of Mass by aligning the connection mechanism accordingly thereby preventing module from toppling.
- Size and placement of wheels for stability and speed enhancement.
- Establishing communication and speed control
- Alignment of DC motor and wheels for balanced motion

10

Morphius : A self-reconfiguring modular robot

### 7 Further Planning

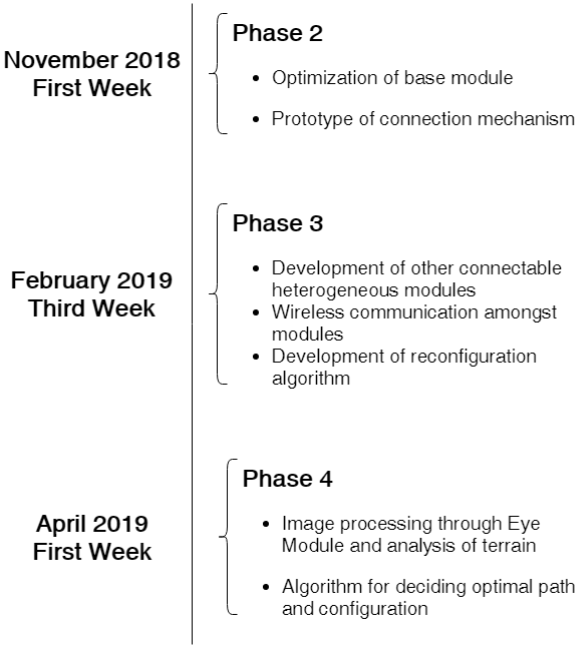
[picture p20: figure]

11

Morphius : A self-reconfiguring modular robot

### References

[1] Hossein Ahmadzadeh, Ellips Masehian, and Masoud Asadpour. Modular robotic systems: characteristics and applications. Journal of Intelligent & Robotic Systems, 81(3-4):317–357, 2016.
[2] Andres Castano, Wei-Min Shen, and Peter Will. Conro: Towards deployable robots with inter-robots metamorphic capabilities. Autonomous Robots, 8(3):309–324, 2000.
[3] Jay Davey, Ngai Kwok, and Mark Yim. Emulating self-reconfigurable robots-design of the smores system. In Intelligent Robots and Systems (IROS), 2012 IEEE/RSJ International Conference on, pages 4464–4469. IEEE, 2012.
[4] Robert Fitch, Zack Butler, and Daniela Rus. Reconfiguration planning for heterogeneous self-reconfiguring robots. In Intelligent Robots and Systems, 2003.(IROS 2003). Proceedings. 2003 IEEE/RSJ International Conference on, volume 3, pages 2460– 2467. IEEE, 2003.
[5] Haruhisa Kurokawa, Kohji Tomita, Akiya Kamimura, Shigeru Kokaji, Takashi Hasuo, and Satoshi Murata. Distributed self-reconfiguration of m-tran iii modular robotic system. The International Journal of Robotics Research, 27(3-4):373–386, 2008.
[6] Ch S Sankhar Reddy, Anita Agrawal, KR Anupama, et al. Sq-bot-a modular robot prototype for self-reconfiguring structures. In Robotics: Current Trends and Future Challenges (RCTFC), International Conference on, pages 1–6. IEEE, 2016.
[7] Masahiro Shimizu, Takuma Kato, Max Lungarella, and Akio Ishiguro. Adaptive reconfiguration of a modular robot through heterogeneous inter-module connections. In Robotics and Automation, 2008. ICRA 2008. IEEE International Conference on, pages 3527–3532. IEEE, 2008.

12

Morphius : A self-reconfiguring modular robot

[8] Alexander Spr¨owitz, | Rico Moeckel, | Massimo Vespignani,
St´ephane Bonardi, and Auke Jan Ijspeert. Roombots: A hardware perspective on 3d self-reconfiguration and locomotion with a homogeneous modular robot. Robotics and Autonomous Systems, 62(7):1016–1033, 2014.
[9] Mark Yim, David G Duff, and Kimon Roufas. Modular reconfigurable robots, an approach to urban search and rescue. In Proceedings of the 1st International Workshop on Human-friendly Welfare Robotics Systems, Taejon, Korea, 2000.
[10] Jie Zhao, Xindan Cui, Yanhe Zhu, and Shufeng Tang. A new self-reconfigurable modular robotic system ubot: Multi-mode locomotion and self-reconfiguration. In Robotics and automation (ICRA), 2011 IEEE International Conference on, pages 1020– 1025. IEEE, 2011.

13

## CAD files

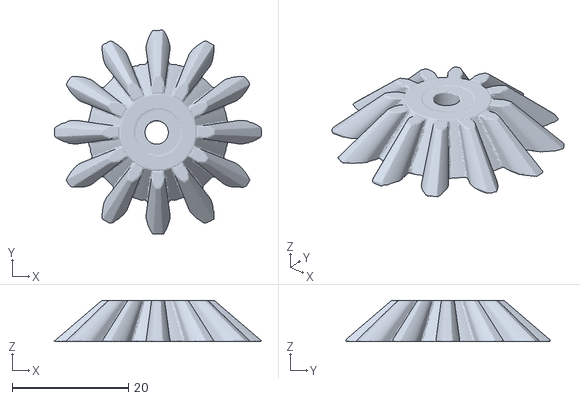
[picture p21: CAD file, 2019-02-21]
Phase_3/3D MODELS/3D Print Files/gear3 binary.stl
35.5 x 35.1 x 7.07

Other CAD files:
Phase_4/LaserCutting/base modules v2.dwg
Phase_3/3D MODELS/Complete_Connector Main v9.f3d
Phase_4/3Dprinting/BEVELGEARSFORMORPH v16.f3d

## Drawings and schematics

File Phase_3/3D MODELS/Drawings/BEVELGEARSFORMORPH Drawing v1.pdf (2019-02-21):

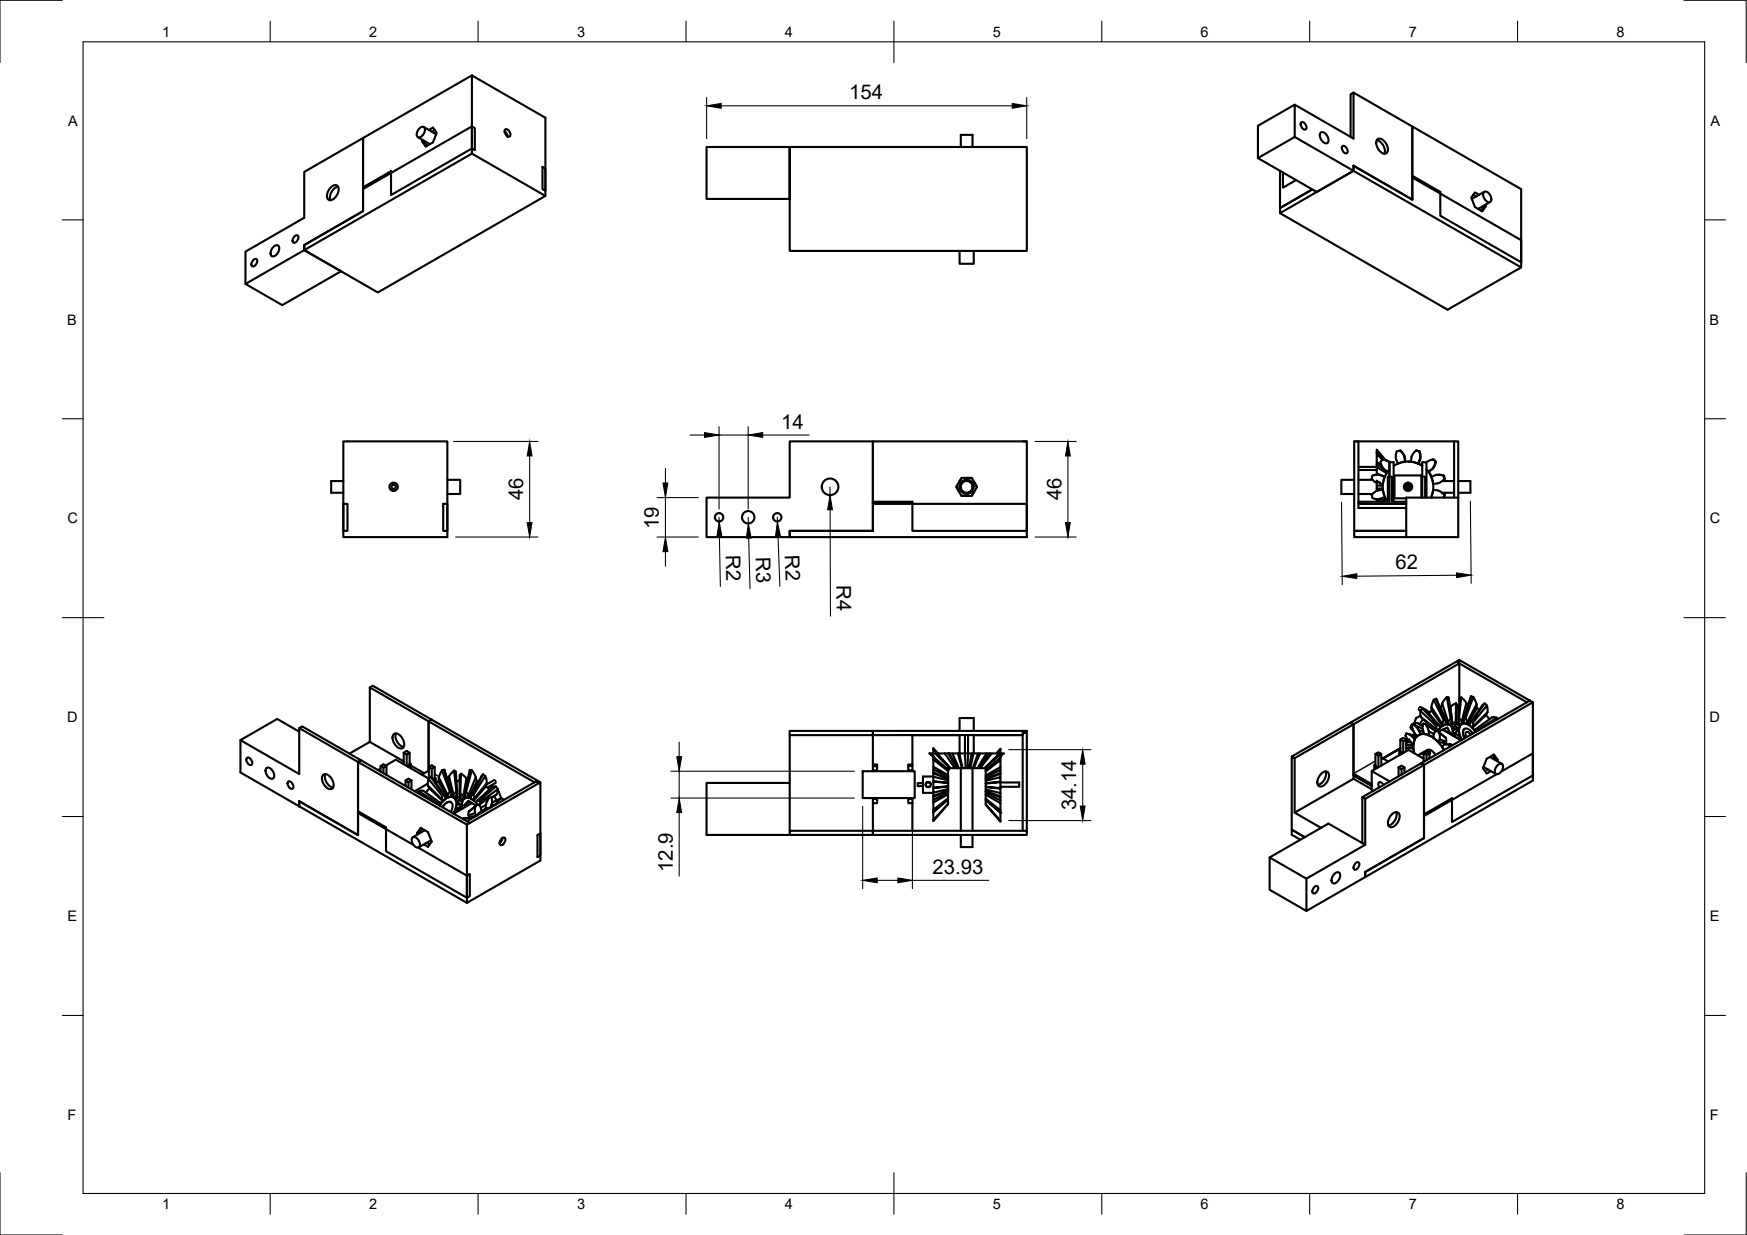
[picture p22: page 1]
8 BCDEF; ABCDEF

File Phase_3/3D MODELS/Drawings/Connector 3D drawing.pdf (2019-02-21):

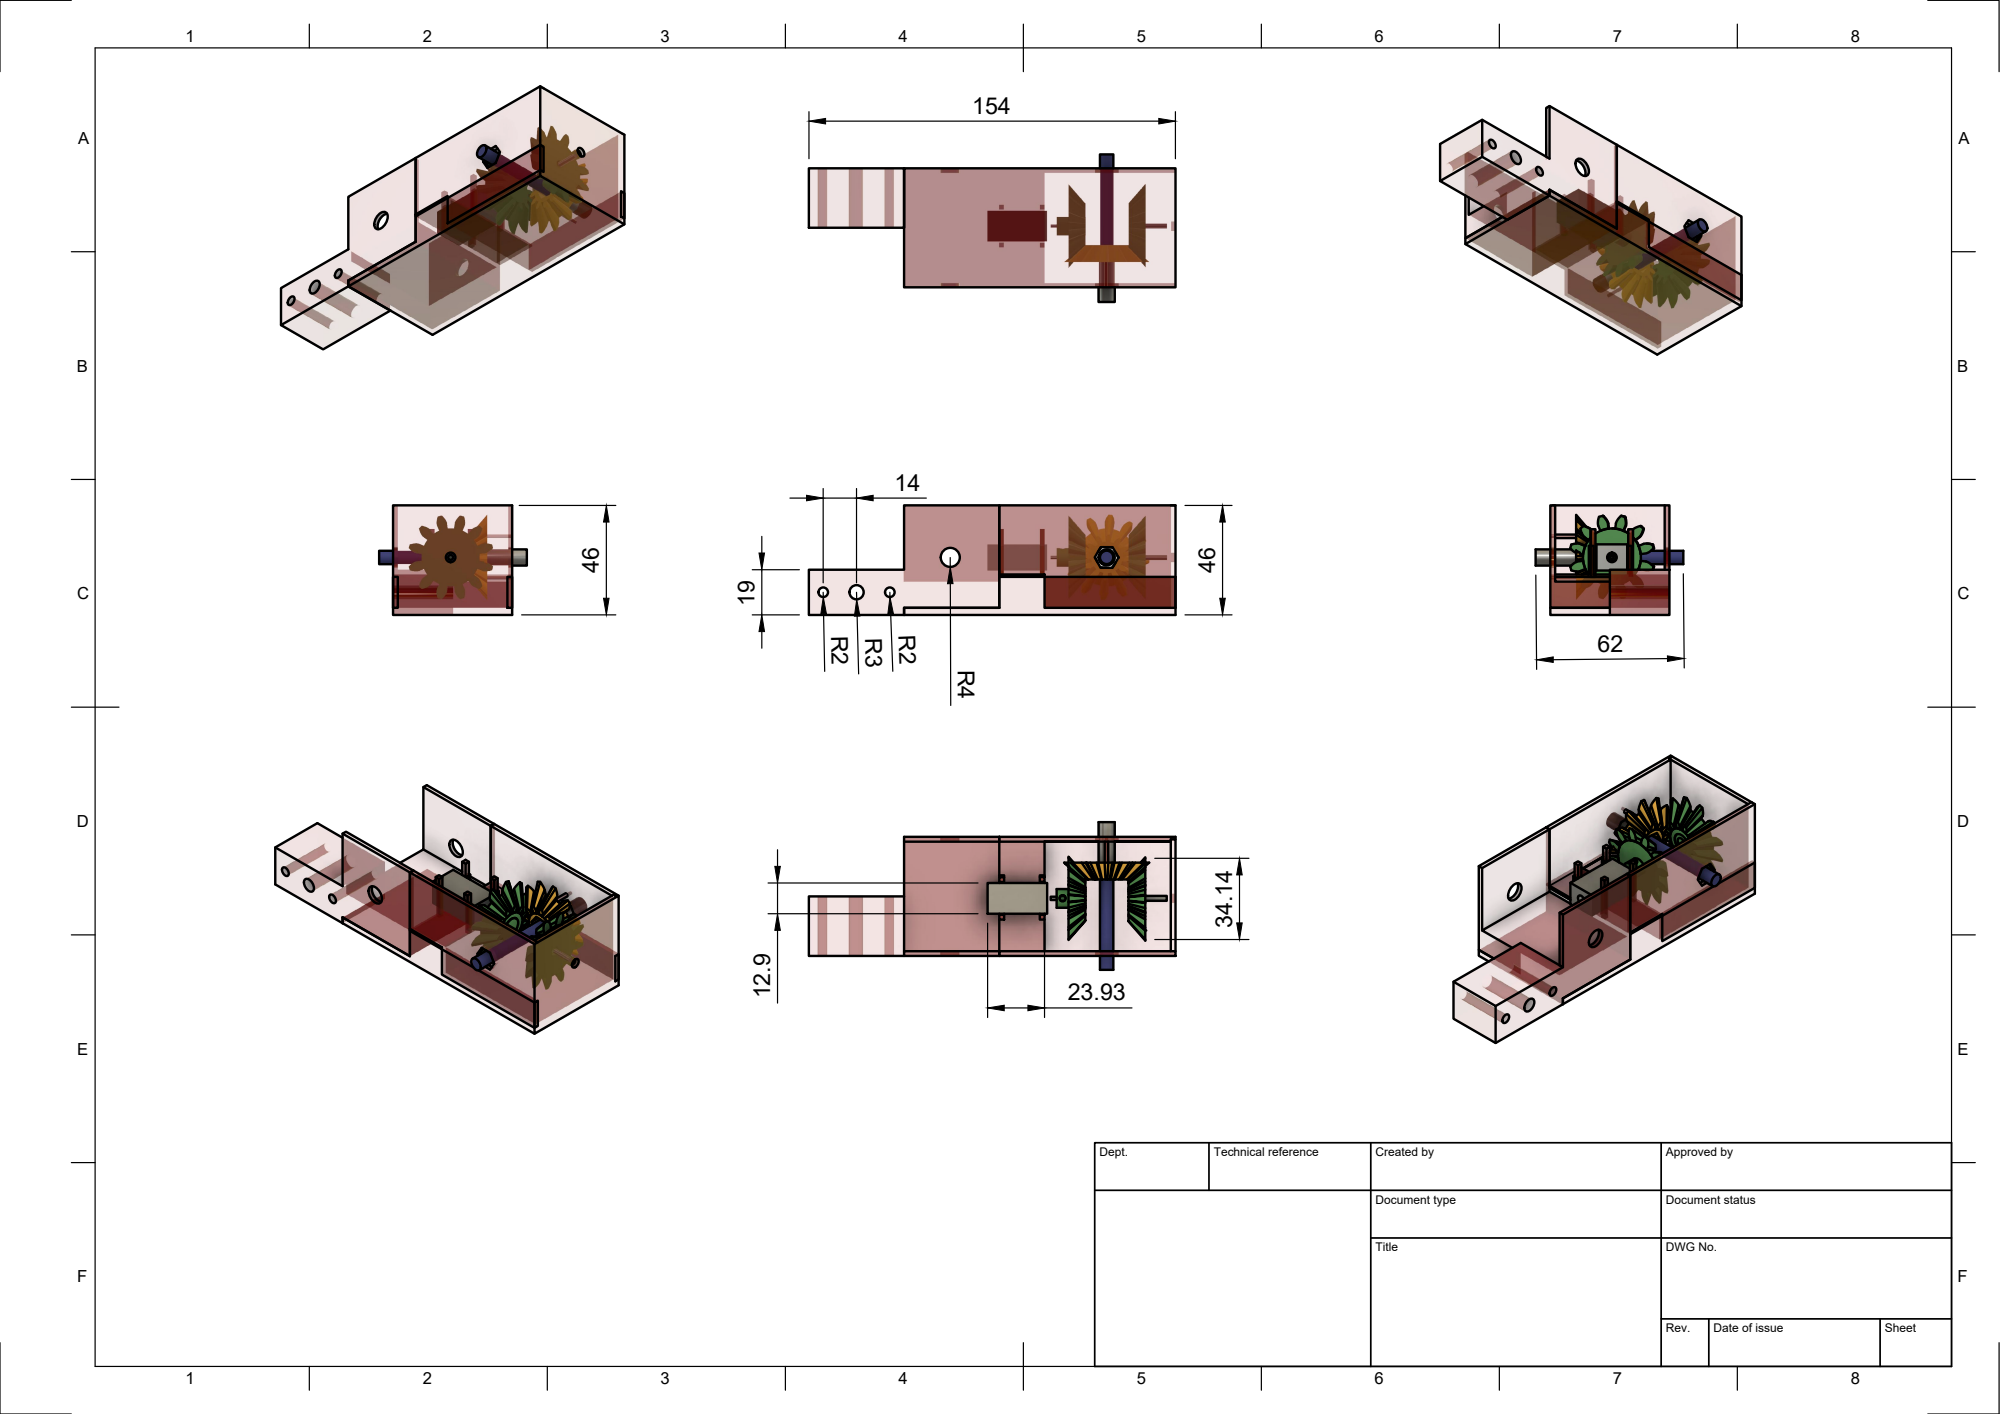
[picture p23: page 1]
Rev.; Date of issue; Sheet 34.14 12.9

Dept. | Technical reference | Created by | Approved by

Document type | Document status

Title | DWG No.

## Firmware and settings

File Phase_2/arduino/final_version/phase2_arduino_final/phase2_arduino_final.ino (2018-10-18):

#include <SoftwareSerial.h>
#include <Servo.h>

int E=6;  // Enable Pin for motor 1
SoftwareSerial mySerial(8,9);   //BLE RX||TX
Servo myservo;  // create servo object to control a servo
// twelve servo objects can be created on most boards
int i = 0;
int pos = 0;    // variable to store the servo position
char c;
void setup()
{
myservo.attach(3);       //servo motor pwm given from this port
mySerial.begin(9600);   //BLE serial communication baud rate set
Serial.begin(9600);   
delay(100);
pinMode(4, OUTPUT);//pins 4&5 for l293d: controlling direction of motion
pinMode(5, OUTPUT);
pinMode(E, OUTPUT);//pwm providing output
}
void loop()
{
if (Serial.available()>0)
mySerial.write(Serial.read());   
if (mySerial.available()>0)  //checks serial data received from app via BLE
{
c = mySerial.read();
if(c == 3)  //for arm control of the base module
{
  Serial.write(c);
  for (pos = 0; pos <= 180; pos += 1) 
    { 
    myservo.write(pos);              // tell servo to go to position in variable 'pos'
    delay(15);                       // waits 15ms for the servo to reach the position
    }
  for (pos = 180; pos >= 0; pos -= 1) 
  { 
    myservo.write(pos);              // tell servo to go to position in variable 'pos'
    delay(15);                       // waits 15ms for the servo to reach the position
  }
}
if (c == 1) //for reverse motion 
{
 for(i=0;i<100;i=i+5)
  {
  analogWrite(E, i); //pwm used for smoother operation
  digitalWrite(5,LOW);
  digitalWrite(4,HIGH);
    }
  Serial.write(i); //prints on terminal
  c = 5;
}
delay(1000);
Serial.write(i);
if (c == 0) //for forward motion
{
  for(i=0;i<150;i=i+5)
  {
  analogWrite(E, i);
  digitalWrite(5,HIGH);
  digitalWrite(4,LOW);
    }
  Serial.write(i);
  c = 5;
}
if (c == 2)  //for stopping the module
{
  for(; i>=0; i = i-10)
  {
    analogWrite(E, i);
  } 
  digitalWrite(4,LOW);
  digitalWrite(5,LOW);
}
}
}

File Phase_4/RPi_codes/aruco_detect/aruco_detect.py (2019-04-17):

import numpy as np
import cv2
import cv2.aruco as aruco
import math

# import the necessary packages
from picamera.array import PiRGBArray
from picamera import PiCamera
import time

# initialize the camera and grab a reference to the raw camera capture
camera = PiCamera()
camera.resolution = (640, 480)
camera.framerate = 4
rawCapture = PiRGBArray(camera, size=(640, 480))


camera_matrix = None
dist_coeff = None
#cap = cv2.VideoCapture(0)
global aruco_dict
aruco_dict = aruco.Dictionary_get(aruco.DICT_5X5_250)
D = 24
W = 11
F = 300
def getCameraMatrix():
        global camera_matrix, dist_coeff
        with np.load('Camera.npz') as X:
                camera_matrix, dist_coeff, _, _ = [X[i] for i in ('mtx','dist','rvecs','tvecs')]
        return camera_matrix,dist_coeff

cam, dist_coeff = getCameraMatrix()
for frame in camera.capture_continuous(rawCapture, format="bgr", use_video_port=True):
    # Capture frame-by-frame
    #ret, frame = cap.read()
    image = frame.array
    parameters = aruco.DetectorParameters_create()
    corners, ids, _ = aruco.detectMarkers(image, aruco_dict,parameters = parameters)
    rvec, tvec,_ = aruco.estimatePoseSingleMarkers(corners,0.1, cam, dist_coeff)
    
    aruco.drawDetectedMarkers(image,corners)
    if (np.any(ids!=None)):
        aruco.drawAxis(image,cam,dist_coeff,rvec[0],tvec[0],0.1)
        P=corners[0][0][0][0]-corners[0][0][1][0]
        dist=(F*W)/P
        #print("dist is ",dist)
        cv2.putText(image, "%.2f" % (dist),
		(image.shape[1] - 200, image.shape[0] - 30), cv2.FONT_HERSHEY_SIMPLEX,
		1.0, (0, 255, 255), 3)
        print ('x = '+str(tvec[0][0][0]*100)+'y = '+str(tvec[0][0][1]*100)+'z = '+str(tvec[0][0][2]*100))
        
    # Display the resulting frame
    cv2.imshow('frame',image)
    rawCapture.truncate(0)
    if cv2.waitKey(1) & 0xFF == ord('q'):
        break

# When everything done, release the capture
#cap.release()
#cv2.destroyAllWindows()

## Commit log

2018-10-17 Phase 2 folder added. Arduino files added
2018-10-17 added Evo app files of the initial stages. Edit index.html file for necessary changes.
2018-10-18 Final version of arduino file has been added. Just for phase 2.
2019-02-21 Phase 3 files have been uploaded and updated to the latest version.
    [Complete_Connector Main v9.f3d, gear3 binary.stl]
2019-04-17 Phase 4 files have been updated
    [BEVELGEARSFORMORPH v16.f3d, base modules v2.dwg]
